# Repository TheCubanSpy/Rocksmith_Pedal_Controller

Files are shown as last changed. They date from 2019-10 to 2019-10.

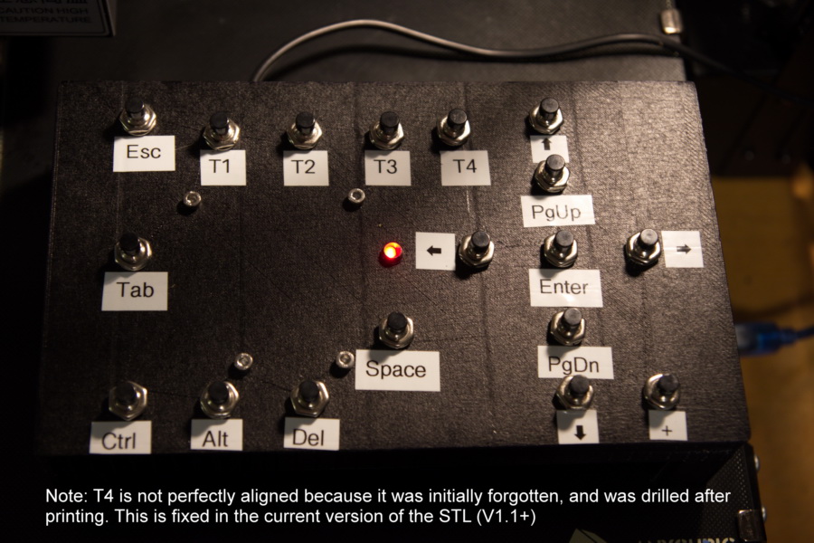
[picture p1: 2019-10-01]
Rocksmith_Pedal_1.jpg

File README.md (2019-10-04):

# Rocksmith_Pedal_Controller
Arduino-powered, 3D-printed pedal/controller for Rocksmith 2014

Video: https://youtu.be/t0BvcK5xxLA

Print settings:

Printed in PETG on an Anycubic I3 Mega-S 

Layer height 0.2

Blue painter's tape over the Ultrabase (otherwise PETG will likely fuse to your build surface)

Nozzle 230C, Bed 75C

Print speed 30mm/s

Cooling fan off

The design uses kellyegan's Arduino OpenSCAD mounting library V2.0: https://www.thingiverse.com/thing:64008

Parts List:

-Buttons: https://www.amazon.ca/gp/product/B07Q6C3NSN/ref=ppx_yo_dt_b_asin_title_o01_s00?ie=UTF8&psc=1

-Arduino Leonardo with headers

-LED mount: https://www.amazon.ca/gp/product/B00NWFHA12/ref=ppx_yo_dt_b_asin_title_o01_s00?ie=UTF8&psc=1

-4xM3 25mm bolts,3xM3 nuts (one of the nuts won't fit due to the Arduino header)

-Female Header strip (I used one of these for ground with the pins soldered together, and simply taped it to the bottom/back of the pedal with electrical tape): https://www.amazon.ca/gp/product/B012C59FQA/ref=ppx_yo_dt_b_asin_title_o09_s00?ie=UTF8&psc=1. There are better and simpler ways for a ground, but I decided to use this since it was onhand and wasn't useful for much else.

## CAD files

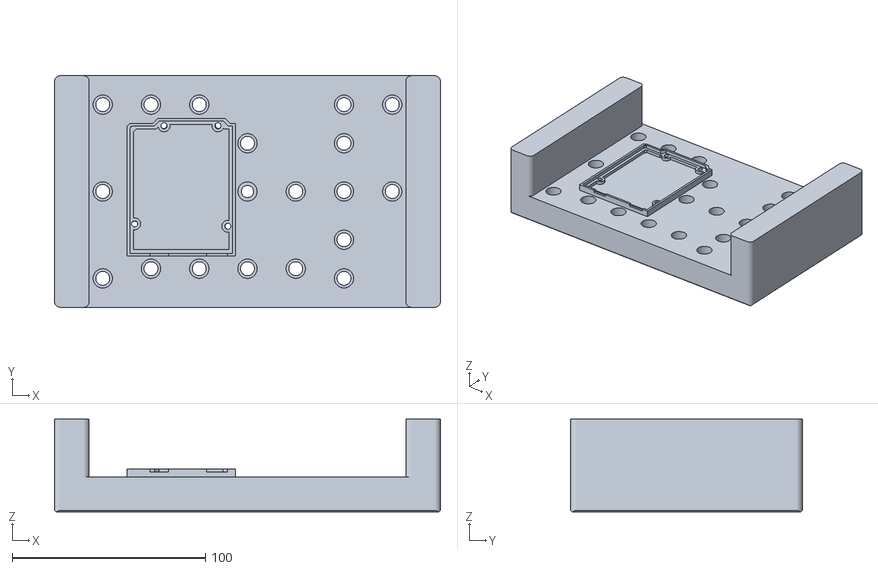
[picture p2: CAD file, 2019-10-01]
Rocksmith_board.stl
200.0 x 120.0 x 48.0

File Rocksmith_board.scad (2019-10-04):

include <Arduino_OpenSCAD_mounting_library_(v2.0)\arduino.scad>
module roundedcube(xdim ,ydim ,zdim,rdim)
{
    hull(){
        translate([rdim,rdim,0])cylinder(h=zdim,r=rdim);
        translate([xdim-rdim,rdim,0])cylinder(h=zdim,r=rdim);
        translate([rdim,ydim-rdim,0])cylinder(h=zdim,r=rdim);
        translate([xdim-rdim,ydim-rdim,0])cylinder(h=zdim,r=rdim);
    }
}
module board_face()
{
    roundedcube(200,120,18,3);
}
module arduinohole()
{
    cylinder (h=20, r=(3.2/2));
} 
module leg()
{
    roundedcube(18,120,30,3);
}
module led_top()
{
    cylinder(h=3,r=3.2);
}
module button_top()
{
    cylinder(h=3,r=3.6);
}    
module button_bottom()
{
    cylinder(h=15,r=5);
}    
module button()
{
    translate([0,0,15])button_top();
    translate([0,0,0])button_bottom();
}
module led()
{
    translate([0,0,15])led_top();
    translate([0,0,0])button_bottom();
}
module cutaway()
{
    cube([200,120,18],center=true); //Used to taper off the edges of the top surface slightly
}
module board()
{
    difference()
    {
        board_face();
        translate([175,60,0]) button();//Right arrow
        translate([125,60,0]) button();//Left Arrow
        translate([150,85,0]) button();//Up Arrow
        translate([150,35,0]) button();//Down Arrow
        translate([150,105,0]) button();//Page Up
        translate([150,15,0]) button();//Page Down
        translate([25,105,0]) button();// Escape
        translate([125,100,0]) button();//4 (Tone)
        translate([100,100,0]) button();//3 (Tone)
        translate([75,100,0]) button();//2 (Tone)
        translate([50,100,0]) button();//1 (Tone)
        translate([25,15,0]) button();//Ctrl
        translate([50,15,0]) button();//Alt
        translate([75,15,0]) button();//Del
        translate([25,60,0]) button();//Tab
        translate([100,35,0]) button();//Space 
        translate([175,15,0]) button();//+
        translate([150,60,0])button();//Enter
        
        translate([100,60,0])led();
        
        translate([41.5,77,0]) arduinohole();
        translate([90,78,0]) arduinohole();
        translate([56.6,25.75,0]) arduinohole();
        translate([85,25.75,0]) arduinohole();
    }
    translate([182,0,-30]){
        leg();
    }    

    translate([0,0,-30]){
        leg();
    }   
}
$fn=64;
difference(){
    board();
    translate([100,-30,0]) rotate(45,[1,0,0]) cutaway();
    translate([100,150,0]) rotate(135,[1,0,0]) cutaway();
    translate([-30,60,0]) rotate(135,[0,1,0]) cutaway();
    translate([230,60,0]) rotate(45,[0,1,0]) cutaway();
}

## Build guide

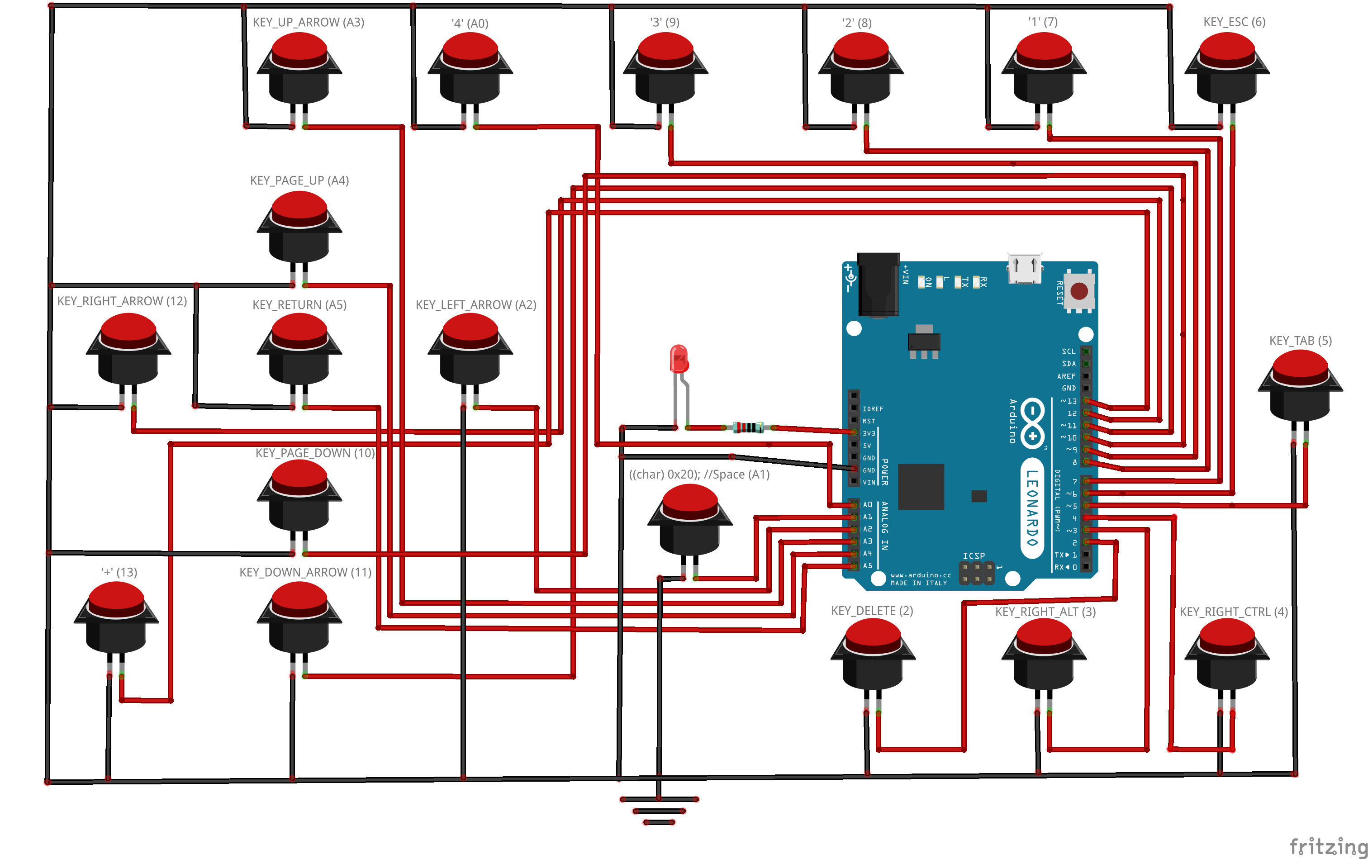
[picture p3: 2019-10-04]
Rocksmith_Pedal_Wiring.png

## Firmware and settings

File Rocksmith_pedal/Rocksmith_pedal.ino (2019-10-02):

/* This code is based on learnelectronics' tutorial video available here: https://www.youtube.com/watch?v=SHIcliL4O14 */

#include <Keyboard.h>

void setup() {
  //LED is no longer handled by a digital IO pin - use 3.3V or 5V pin. 
  pinMode(2, INPUT_PULLUP); 
  pinMode(3, INPUT_PULLUP);
  pinMode(4, INPUT_PULLUP);
  pinMode(5, INPUT_PULLUP);
  pinMode(6, INPUT_PULLUP);
  pinMode(7, INPUT_PULLUP);
  pinMode(8, INPUT_PULLUP);
  pinMode(9, INPUT_PULLUP); 
  pinMode(10, INPUT_PULLUP);
  pinMode(11, INPUT_PULLUP);
  pinMode(12, INPUT_PULLUP);
  pinMode(13, INPUT_PULLUP);
  pinMode(A0, INPUT_PULLUP);       
  pinMode(A1, INPUT_PULLUP);
  pinMode(A2, INPUT_PULLUP);
  pinMode(A3, INPUT_PULLUP);
  pinMode(A4, INPUT_PULLUP);
  pinMode(A5, INPUT_PULLUP); 
}

void loop() {
   // put your main code here, to run repeatedly:
   Keyboard.begin();
   if (digitalRead(2) == 0)
   {
      Keyboard.write(KEY_DELETE);
      delay(200);
   }
   else if (digitalRead(3) == 0)
   {
      Keyboard.write(KEY_RIGHT_ALT);
      delay(200);
   }
   else if (digitalRead(4) == 0)
   {
      Keyboard.write(KEY_RIGHT_CTRL);
      delay(200);
   }
   else if (digitalRead(5) == 0)
   {
      Keyboard.write(KEY_TAB);
      delay(200);
   }
   else if (digitalRead(6) == 0)
   {
      Keyboard.write(KEY_ESC);
      delay(200);
   }
   else if (digitalRead(7) == 0)
   {
      Keyboard.write('1');
      delay(200);
   }
   else if (digitalRead(8) == 0)
   {
      Keyboard.write('2');
      delay(200);
   }
   
   else if (digitalRead(9) == 0)
   {
      Keyboard.write('3');
      delay(200);
   }
   else if (digitalRead(A0) == 0)
   {
      Keyboard.write('4'); 
      delay(200);
   }
   else if (digitalRead(10) == 0)
   {
      Keyboard.write(KEY_PAGE_DOWN);
      delay(100);                   //Shorter delay for Page Down and Page Up
   }
   else if (digitalRead(11) == 0)
   {
      Keyboard.write(KEY_DOWN_ARROW);
      delay(200);
   }
   else if (digitalRead(12) == 0)
   {
      Keyboard.write(KEY_RIGHT_ARROW);
      delay(200);
   }
   else if (digitalRead(13) == 0)
   {
      Keyboard.write('+');
      delay(200);
   }
   else if (digitalRead(A1) == 0)
   {
      Keyboard.write((char) 0x20); //Space
      delay(200);
   }
   else if (digitalRead(A2) == 0)
   {
      Keyboard.write(KEY_LEFT_ARROW);
      delay(200);
   }
   else if (digitalRead(A3) == 0)
   {
      Keyboard.write(KEY_UP_ARROW);
      delay(200);
   }
   else if (digitalRead(A4) == 0)
   {
      Keyboard.write(KEY_PAGE_UP); 
      delay(100);                   //Shorter delay for Page Down and Page Up
   }
    else if (digitalRead(A5) == 0)
   {
      Keyboard.write(KEY_RETURN);
      delay(200);
   } 
   Keyboard.end();
}

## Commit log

2019-10-01 Added forgotten 'T4' Tone option
    [Rocksmith_board.stl]
2019-10-02 Update Rocksmith_pedal.ino
    Removed leftover LED digital IO logic from loop
2019-10-02 Update Rocksmith_pedal.ino
    fixed erroneous comment
    [Rocksmith_pedal.ino]
2019-10-02 Updated README with print settings, Moved Arduino code to a sketch folder
    r
2019-10-04 Added wiring diagram
2019-10-04 Added link to OpenSCAD mounting library in README
2019-10-04 Added OpenSCAD file
    [Rocksmith_board.scad]
